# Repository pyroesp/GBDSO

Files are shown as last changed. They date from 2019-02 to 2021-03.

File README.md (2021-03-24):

# GBDSO

GBDSO Website : http://swelectronics.co.uk/Gameboy/DsoDemo/DsoDemo.htm  
GBDSO Elektor article : http://www.radanpro.com/Radan2400/TestShematics/GameBoyScope.pdf  
GBDSO BOM list (2019/02) : https://docs.google.com/spreadsheets/d/1vu9Xc1Mw5STfz_mAsAOrmmyRrHJMRS4_JKM7iif-KBE/edit#gid=0  

## Max Voltage Ratings

- +/- 16V on 1:1  
- +/- 50V on 10:1  

Do **NOT** exceed the max voltage ratings or you risk damaging the cartridge and the Game Boy.  
I'm not responsible if it blows up!  

## Schematic

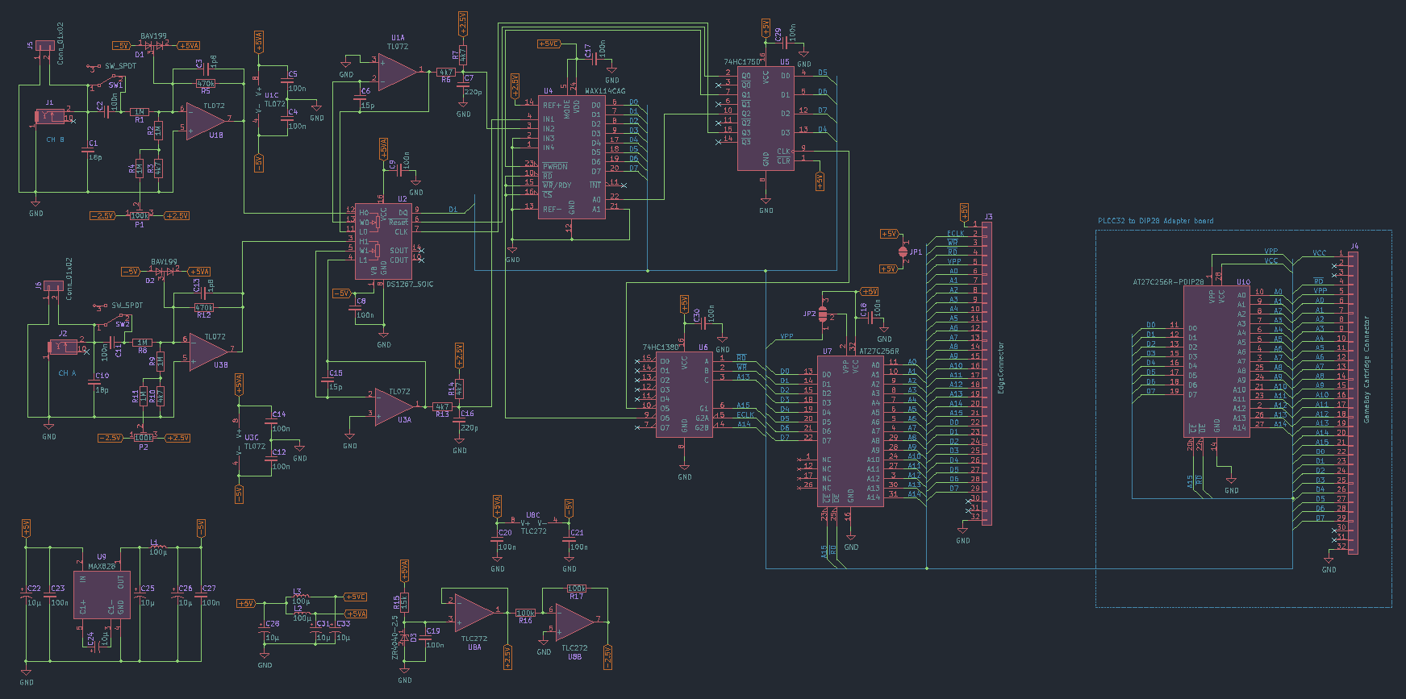
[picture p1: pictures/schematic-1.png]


## PCB

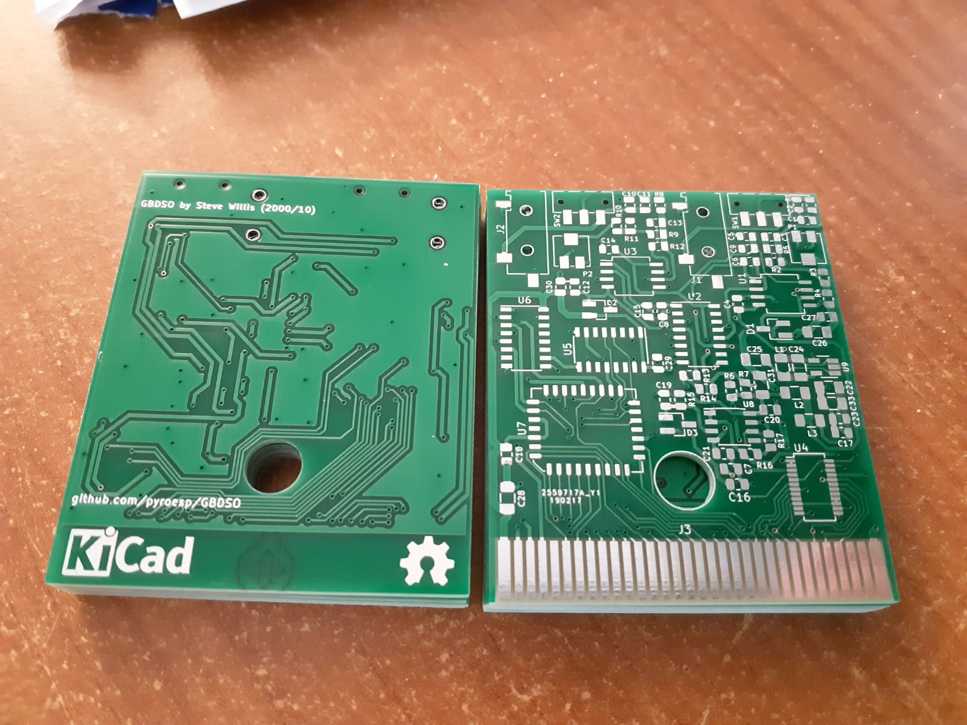
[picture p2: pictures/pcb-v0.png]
   
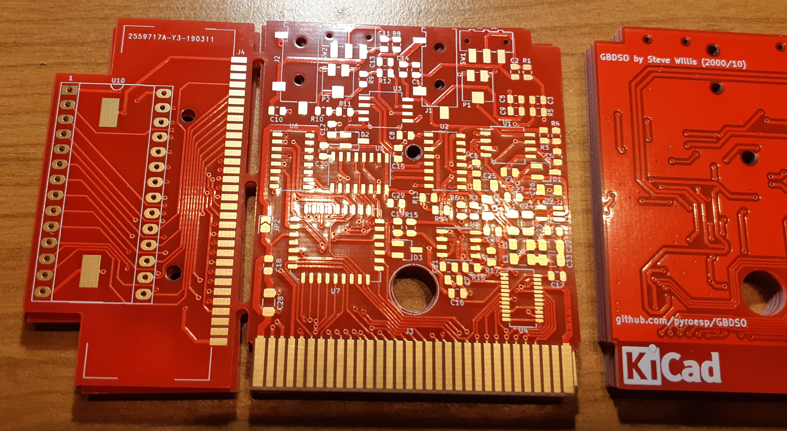
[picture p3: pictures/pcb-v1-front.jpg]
   
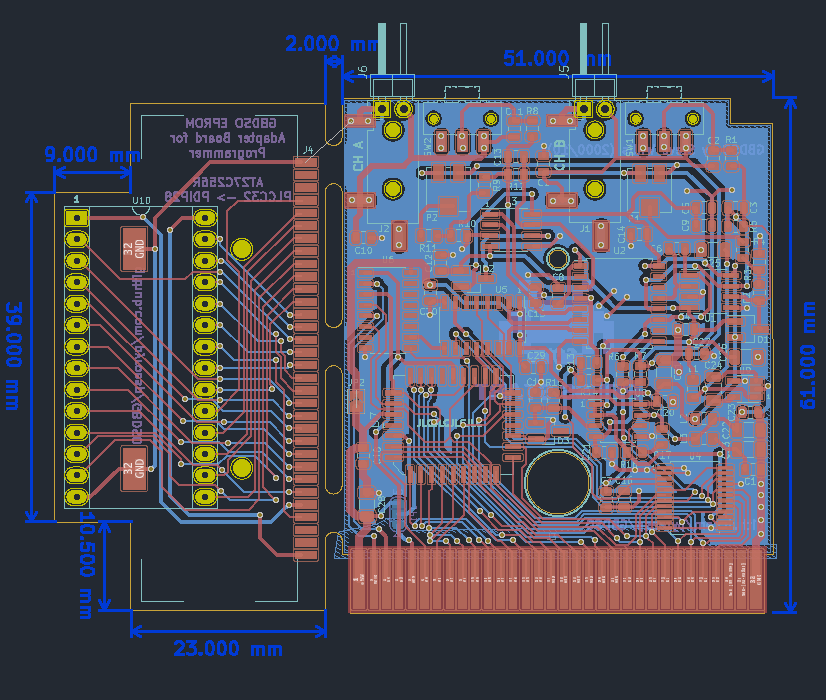
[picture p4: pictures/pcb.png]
  
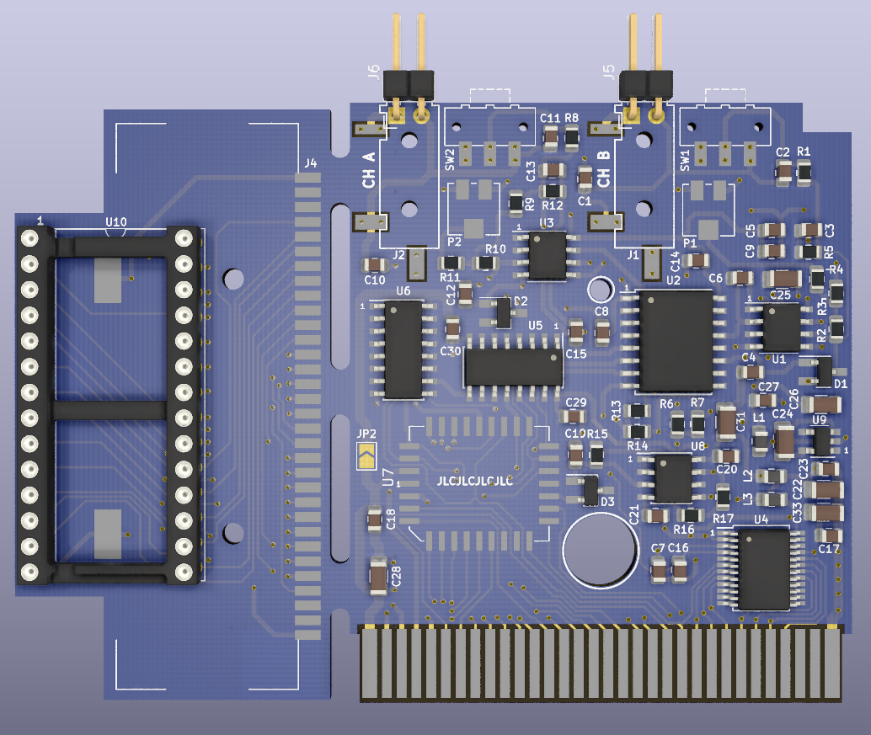
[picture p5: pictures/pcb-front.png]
  
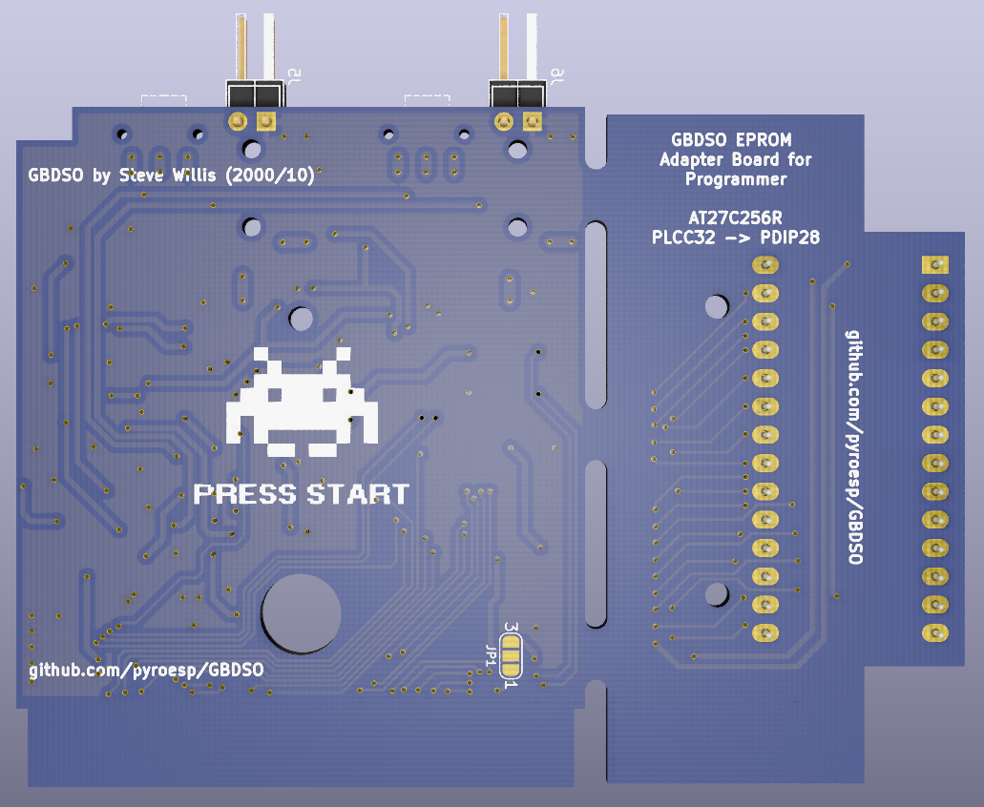
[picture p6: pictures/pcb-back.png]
   
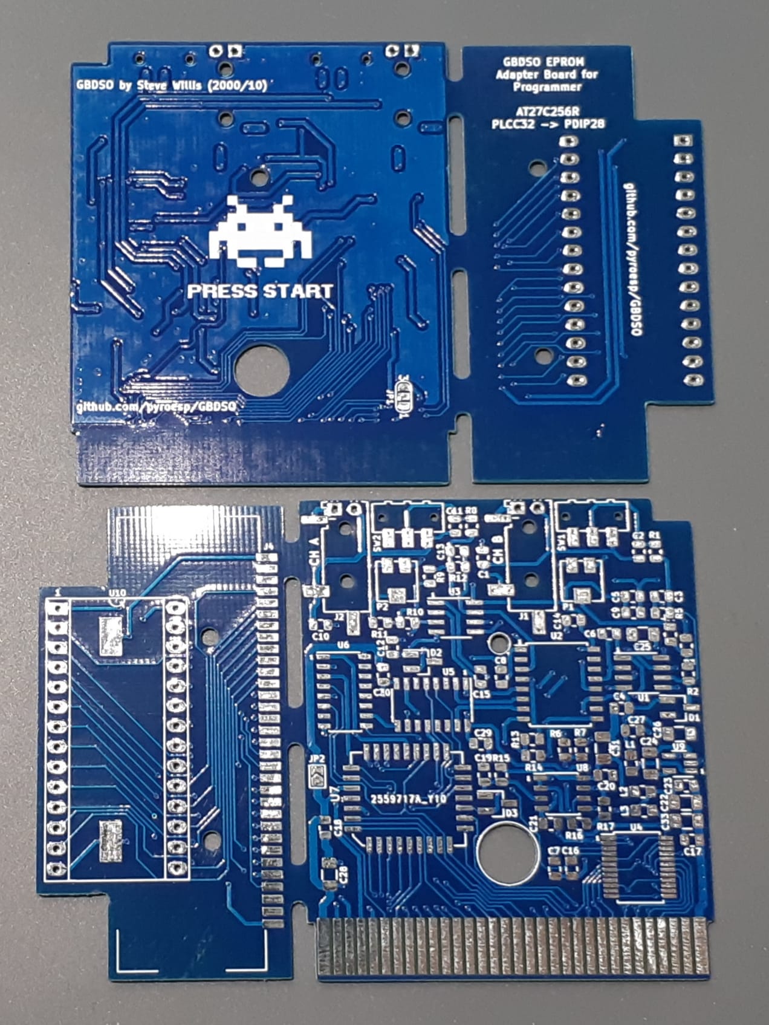
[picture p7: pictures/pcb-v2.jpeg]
   
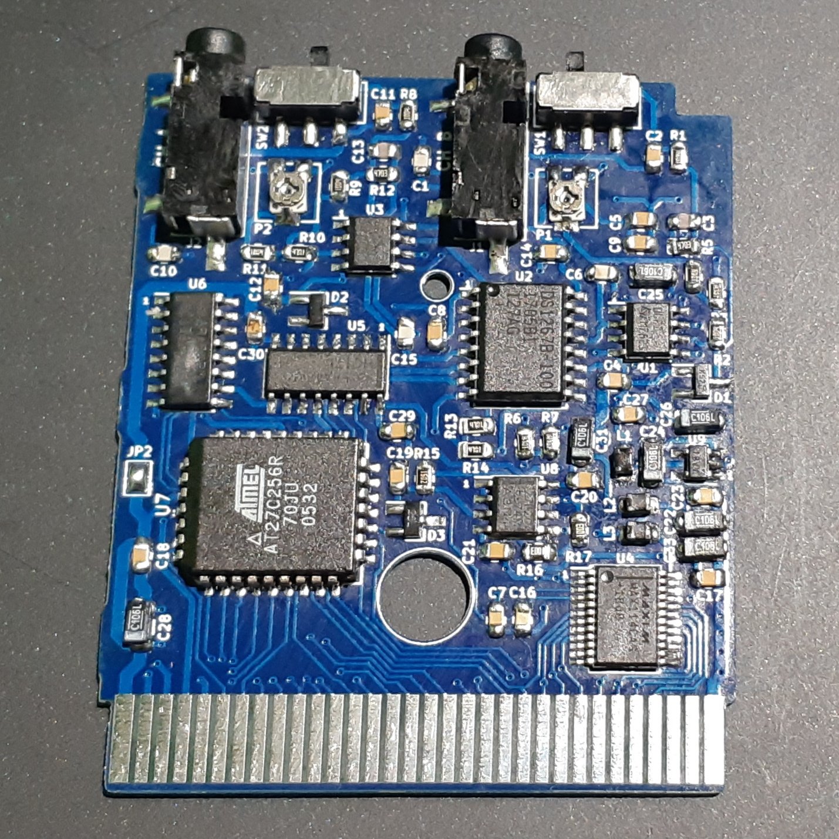
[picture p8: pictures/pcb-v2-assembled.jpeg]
   

## Game Boy test

Since the big v2 update on 2021/01/08, this GBDSO board works on both channels.  
See pictures below:  

   
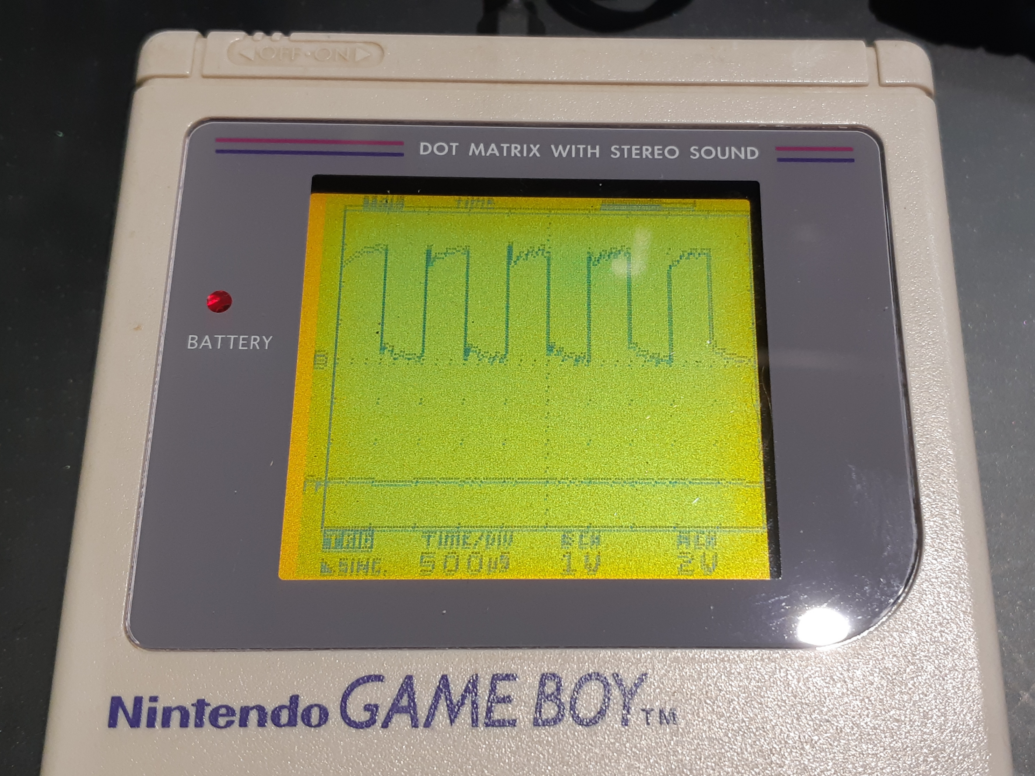
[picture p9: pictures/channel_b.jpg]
   

## Official game cart dimensions

Below you'll find the dimensions for the PCB of an official game (Pokémon Yellow JAP).  

 

## Programming the AT27C256R

The first jumper JP1 selects either 5V to pin 2 of the PROM (VPP) and VPP from the unused 5th edge connector.  
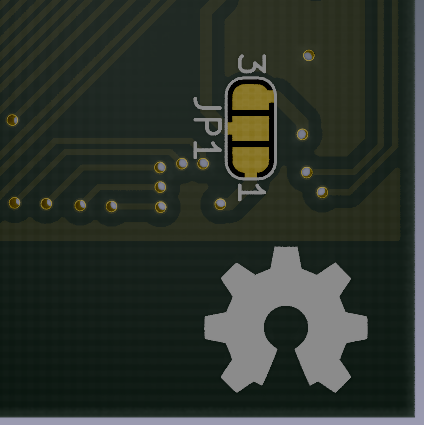
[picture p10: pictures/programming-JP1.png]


The second jumper JP2 cuts the power going to the rest of the board.  
While in programming mode, the PROM needs 6.5V to VCC and I'd rather not have it power to the rest of the board.  
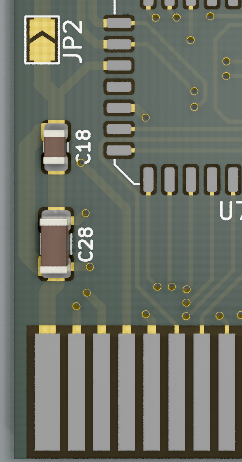
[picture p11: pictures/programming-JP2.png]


To program the PROM, leave JP2 open and set JP1 so that the edge connector VPP is connected to the PROM VPP.  
When programming is done, bridge JP2 and set JP1 so that 5V go to the PROM VPP.  

## GBDSO PROM to PDIP28  

Any decent Universal Programmer should be able to program the PROM on the cart.  
You can see the adapter board on the 3D rendered board above.  

The Game Boy connector uses the Xunbeifang GNI172 footprint made by **obskyr** from the <a href="https://github.com/gbdev/awesome-gbdev">gbdev discord</a>.  
You can find other Game Boy connectors made by **Gekkio** here: <a href="https://github.com/Gekkio/gekkio-kicad-libs">gekkio-kicad-libs</a>.  

The Xunbeifang GNI172 can be found on <a href="https://www.aliexpress.com/item/For-Nintendo-DS-NDSL-GBA-Game-Cartridge-Card-Reader-Slot-Repair-Part/32679592016.html">aliexpress</a>.

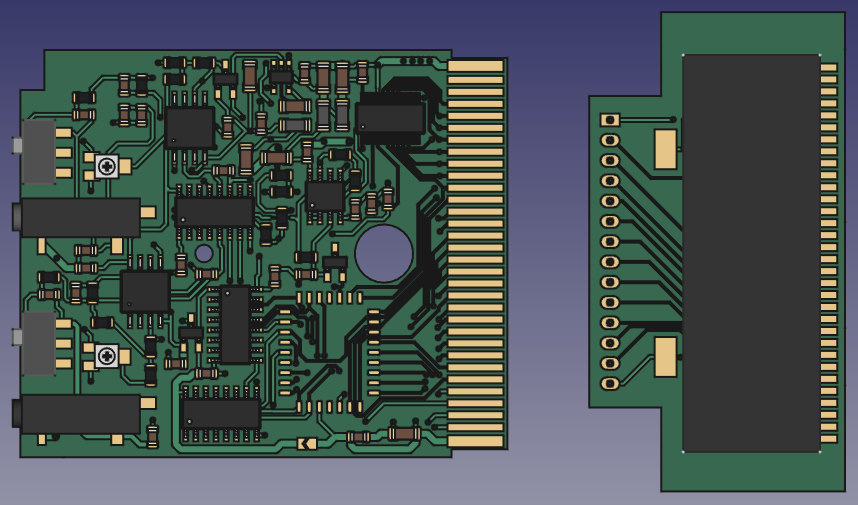
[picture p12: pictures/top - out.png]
  
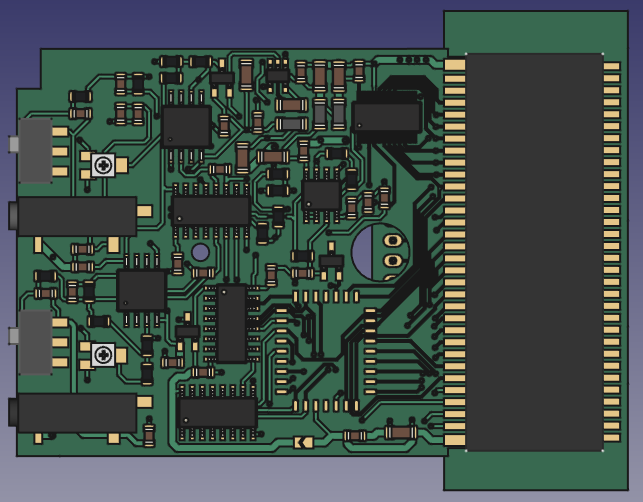
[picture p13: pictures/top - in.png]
  

To program the PROM, leave JP1 open and close JP2 as shown below.
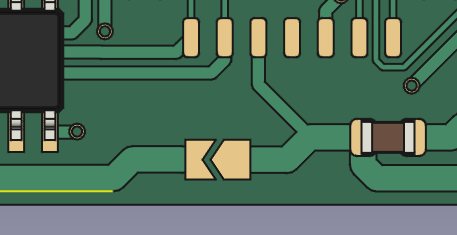
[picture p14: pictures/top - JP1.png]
  
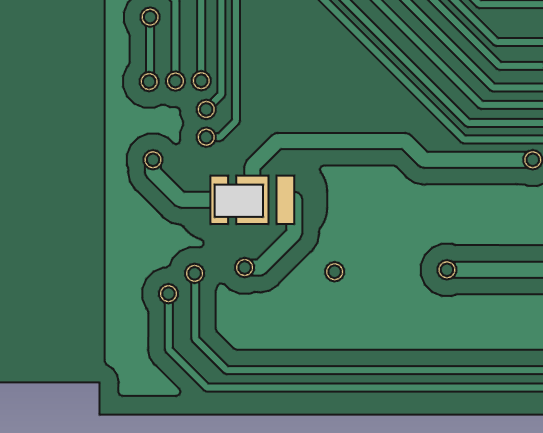
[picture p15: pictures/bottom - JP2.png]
  

Plug the adapter board into a Universal Programmer and set the target device to DIP28 AT27C256R.
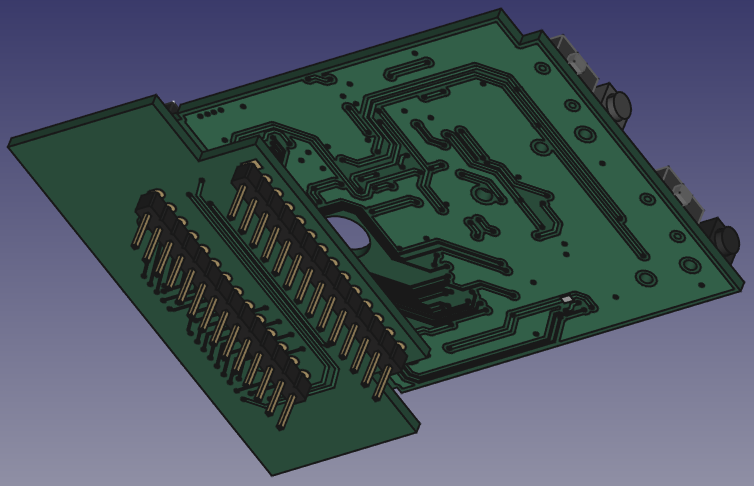
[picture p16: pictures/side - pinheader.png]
  

Note: This part of the board has not been tested yet, so I hope it works.

## Original GBDSO

Original GBDSO pictures from November 2000 courtesy of **Tauwasser** on the <a href="https://github.com/gbdev/awesome-gbdev">gbdev discord</a>.

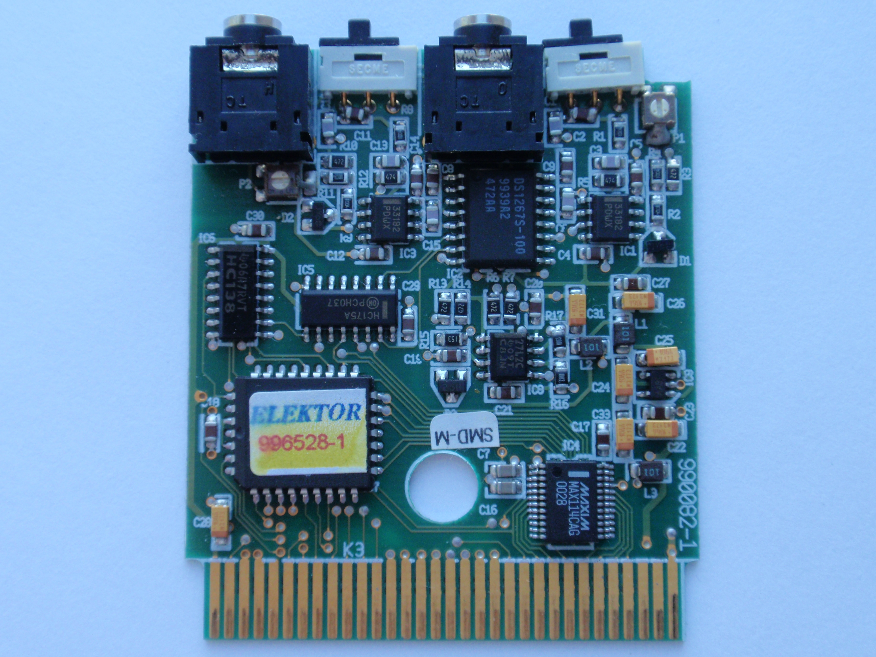
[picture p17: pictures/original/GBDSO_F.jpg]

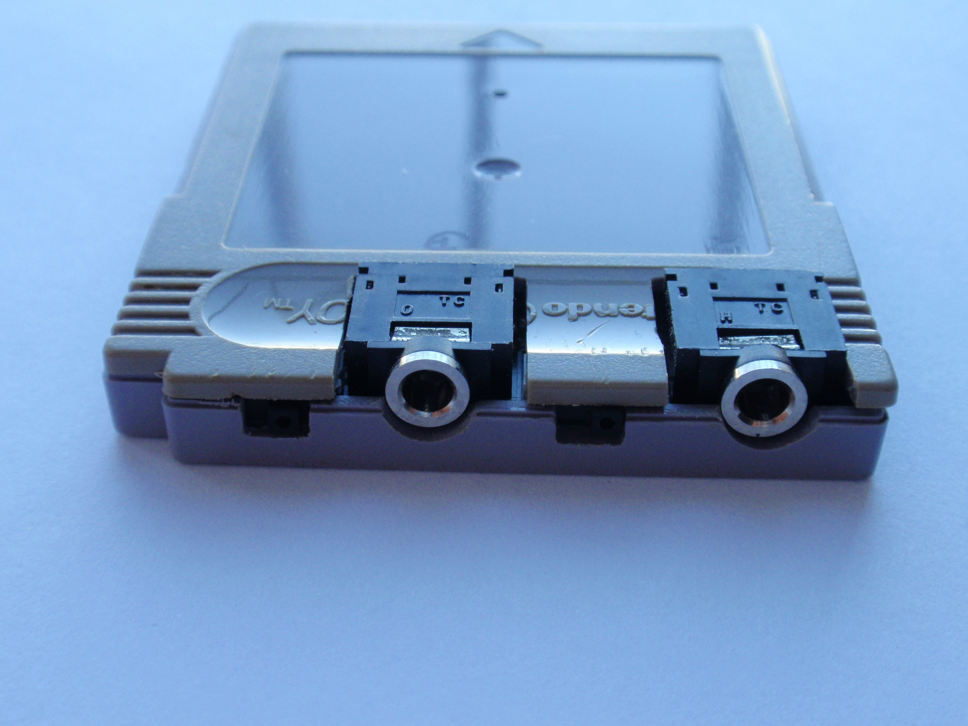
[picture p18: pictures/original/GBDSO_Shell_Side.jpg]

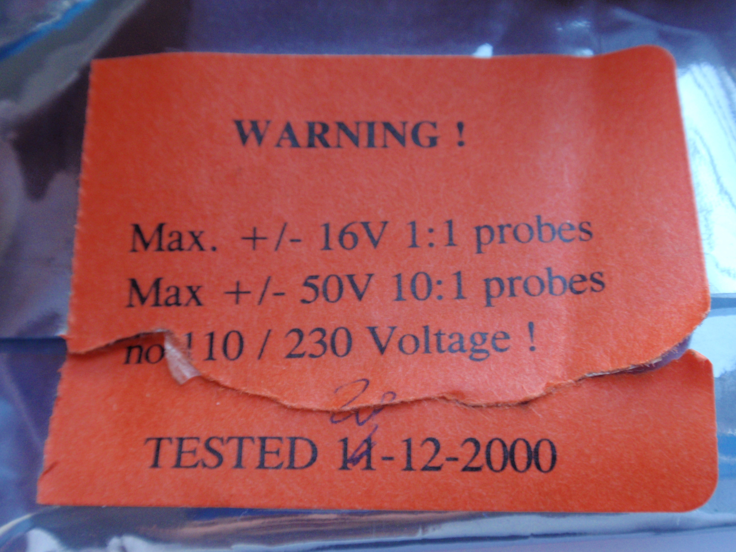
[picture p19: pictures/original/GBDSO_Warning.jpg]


## BOM list

| Label | Value / Name | Price per unit | Number | Total Price | Link |
|---|---|---|---|---|---|
| R1, R2, R4, R8, R9, R11 | 1M | 0.09 | 6 | 0.54 | https://www.digikey.be/product-detail/en/bourns-inc/CR0805-FX-1004ELF/CR0805-FX-1004ELFCT-ND/3740924 |
| R15 | 15k | 0.09 | 1 | 0.09 | https://www.digikey.be/product-detail/en/bourns-inc/CR0805-FX-1502ELF/CR0805-FX-1502ELFCT-ND/3740926 |
| R5, R12 | 470k | 0.09 | 2 | 0.18 | https://www.digikey.be/product-detail/en/RC0805FR-07470KL/311-470KCRCT-ND/730924/?itemSeq=284203171 |
| R3, R6, R7, R10, R13, R14 | 4k7 | 0.09 | 6 | 0.54 | https://www.digikey.be/product-detail/en/CR0805-FX-4701ELF/CR0805-FX-4701ELFCT-ND/3925402/?itemSeq=284203192 |
| R16, R17 | 100k | 0.09 | 2 | 0.18 | https://www.digikey.be/product-detail/en/yageo/RC0805FR-07100KL/311-100KCRCT-ND/730491 |
| P1, P2 | 100k | 0.24 | 2 | 0.48 | https://www.digikey.be/product-detail/en/bourns-inc/TC33X-2-104E/TC33X-104ECT-ND/612912 |
| C1, C10 | 18p | 0.12 | 2 | 0.24 | https://www.digikey.be/product-detail/en/yageo/CC0805JRNPO9BN180/311-1102-1-ND/303012 |
| C2, C4, C5, C8, C9, C11, C12, C14, C17-C21, C23, C27, C29, C30 | 100n | 0.09 | 17 | 1.53 | https://www.digikey.be/product-detail/en/CL21B104KBCNNNC/1276-1003-1-ND/3889089/?itemSeq=284204783 |
| C3, C13 | 1p8 | 0.09 | 2 | 0.18 | https://www.digikey.be/product-detail/en/samsung-electro-mechanics/CL21C1R8CBANNNC/1276-2599-1-ND/3890685 |
| C6, C15 | 15p | 0.1 | 2 | 0.2 | https://www.digikey.be/product-detail/en/wurth-electronics-inc/885012007052/732-7847-1-ND/5454474 |
| C7, C16 | 220p | 0.09 | 2 | 0.18 | https://www.digikey.be/product-detail/en/CL21B221KBANNNC/1276-2474-1-ND/3890560/?itemSeq=284205074 |
| C22, C24, C25, C26, C28, C31, C33 | 10µ 16V | 0.31 | 7 | 2.17 | https://www.digikey.be/product-detail/en/vishay-sprague/293D106X0016A2TE3/718-1956-1-ND/3985805 |
| L1, L2, L3 | 100µ | 0.18 | 3 | 0.54 | https://www.digikey.be/product-detail/en/taiyo-yuden/LBM2016T101J/587-1817-1-ND/1465287 |
| D1, D2 | BAV199 | 0.17 | 2 | 0.34 | https://www.digikey.be/product-detail/en/diodes-incorporated/BAV199-7-F/BAV199-FDICT-ND/1033647 |
| D3 | ZR25D01 -> ZR40402F25TA | 0.61 | 1 | 0.61 | https://www.digikey.be/product-detail/en/diodes-incorporated/ZR40402F25TA/ZR40402F25TACT-ND/243209 |
| IC1, IC3 | MC33182D -> TL072CDT | 0.42 | 2 | 0.84 | https://www.digikey.com/product-detail/en/stmicroelectronics/TL072CDT/497-2200-1-ND/599107 |
| IC2 | DS1267S100 -> DS1267BS-100+ | 5.52 | 1 | 5.52 | https://www.digikey.be/product-detail/en/maxim-integrated/DS1267BS-100/DS1267BS-100-ND/5049982 |
| IC4 | MAX114CAG | 6.9 | 1 | 6.9 | https://www.digikey.be/product-detail/en/maxim-integrated/MAX114CAG/MAX114CAG-ND/1428095 |
| IC5 | 74HC175D | 0.41 | 1 | 0.41 | https://www.digikey.be/product-detail/en/texas-instruments/SN74HC175DR/296-14840-1-ND/562676 |
| IC6 | 74HC138D | 0.34 | 1 | 0.34 | https://www.digikey.be/product-detail/en/texas-instruments/SN74HC138D/296-1193-5-ND/277220 |
| IC7 | AT27C256R-12JC -> AT27C256R-70JU | 1.2 | 1 | 1.2 | https://www.digikey.be/product-detail/en/microchip-technology/AT27C256R-70JU/AT27C256R-70JU-ND/1008583 |
| IC8 | TLC27L2CD | 0.86 | 1 | 0.86 | https://www.digikey.be/product-detail/en/texas-instruments/TLC27L2CDR/296-1316-1-ND/404950 |
| IC9 | MAX828EUK | 4.5 | 1 | 4.5 | https://www.digikey.be/product-detail/en/MAX828EUK%2bT/MAX828EUK%2bTCT-ND/2699369/?itemSeq=284207452 |
| S1, S2 | Slide switch 1 change-over contact | 0.49 | 2 | 0.98 | https://www.digikey.be/product-detail/en/c-k/JS102011SAQN/401-1999-1-ND/1640114 |
| K1, K2 | 3.5mm stereo socket -> mono smd | 0.88 | 2 | 1.76 | https://www.digikey.be/product-detail/en/cui-inc/MJ-3523-SMT-TR/CP-3523MJCT-ND/669691 |

Total Price: 31.31€<br>			
Total Components: 70

## Replacement parts

The input opamps MC33182D is not being sold anymore, at least not on digikey.  
So looking around I thought the TL062 would be a nice replacement but the numbers weren't quite similar.  
I've looked at the TL072 and this one looks pretty good, the only downside is that it isn't a low power opamp.  

If we compare the current consumption from the TL072 and the MC33182D, the TL072 uses 5 times more current (1.4mA typ.) than the MC33182D (420µA).  

Looking further into the MC33182D I found this old forum post talking about replacing it on a GBDSO : [edaboard forum](https://www.edaboard.com/showthread.php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)  
They talked about the TL082, LF412, TLE2082A and TLE2602. Someone used that last one as a replacement for the MC33182D, although digikey has it priced at around 2$ per unit...  

Looking at the information page on TI's website, this is what they say:  
> The TL206x devices are pin-compatible with other TI BiFETs; they can be used to double the bandwidth of TL06x and TL03x circuits, or to reduce power consumption of TL05x, TL07x, and TL08x circuits by nearly 90%.  

That power reduction is crucial for long lasting batteries.  
For now though, I'll try the TL062 I currently have and will try the TL072 on a later date.  
I'll also try to find a suitable, pin-compatible, low power replacement opamp for the TL072.

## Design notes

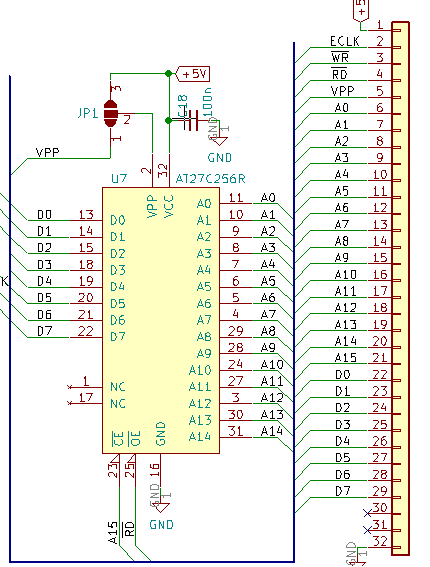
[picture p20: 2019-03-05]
pictures/schematic-eprom.png

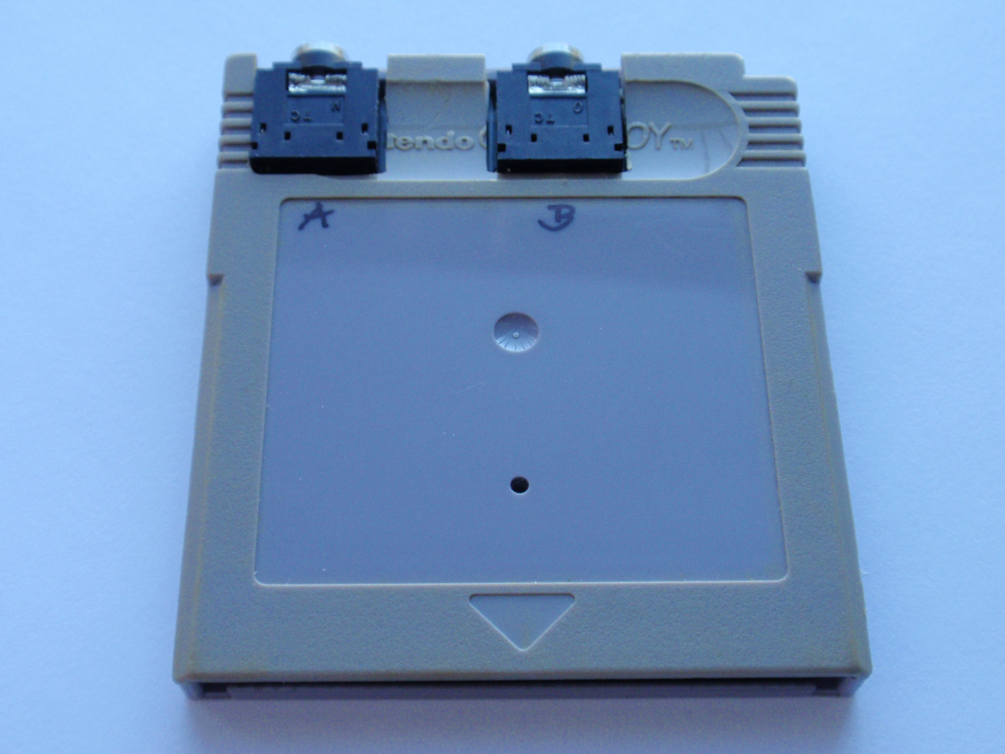
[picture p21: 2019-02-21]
pictures/original/GBDSO_Shell_Top.jpg

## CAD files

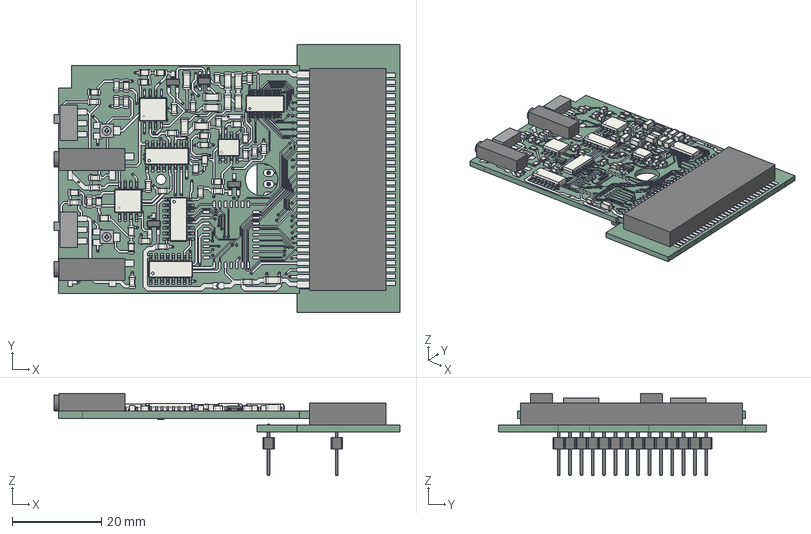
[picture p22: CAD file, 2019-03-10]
freecad/adapter board render/GBDSO 3D model.FCStd
77.5 x 60.0 x 18.4 mm
Pcb
topTracks
botTracks
PinHeader_1x14_P254mm_Vertical
PinHeader_1x14_P254mm_Vertical001
Pcb001
topTracks001
botTracks001
C26_C_1206_3216Metric_5C660075
C23_C_0805_2012Metric_5C8521D1
C1_C_0805_2012Metric_5C865207
C2_C_0805_2012Metric_5C6688FF
C3_C_0805_2012Metric_5C868FB3
C4_C_0805_2012Metric_5C65FEFF
C5_C_0805_2012Metric_5C868FE3
C6_C_0805_2012Metric_5C878DF4
C7_C_0805_2012Metric_5C65FF32
C8_C_0805_2012Metric_5C65FF43
C9_C_0805_2012Metric_5C869043
C10_C_0805_2012Metric_5C84D646
C11_C_0805_2012Metric_5C84B3D2
C12_C_0805_2012Metric_5C65FF87
C13_C_0805_2012Metric_5C65FF98
C14_C_0805_2012Metric_5C8441C3
C15_C_0805_2012Metric_5C65FFBA
C16_C_0805_2012Metric_5C830B5C
C17_C_0805_2012Metric_5C85263F
C18_C_0805_2012Metric_5C65FFED
C19_C_0805_2012Metric_5C6682C5
C20_C_0805_2012Metric_5C66000F
C21_C_0805_2012Metric_5C660020
C22_C_1206_3216Metric_5C8533CB
C24_C_1206_3216Metric_5C660053
C25_C_1206_3216Metric_5C660064
C27_C_0805_2012Metric_5C660086
C28_C_1206_3216Metric_5C86CBE6
C29_C_0805_2012Metric_5C833A80
C30_C_0805_2012Metric_5C662F06
C31_C_1206_3216Metric_5C6600CA
C33_C_1206_3216Metric_5C853338
D1_SOT_23_5C6600F0
D2_SOT_23_5C660105
D3_SOT_23_5C831958
L1_L_1206_3216Metric_5C70B5E1
L2_L_1206_3216Metric_5C66017C
L3_L_1206_3216Metric_5C66018D
R1_R_0805_2012Metric_5C66A901
R2_R_0805_2012Metric_5C86A09A
R3_R_0805_2012Metric_5C660208
R4_R_0805_2012Metric_5C660219
R5_R_0805_2012Metric_5C869013
R6_R_0805_2012Metric_5C66023B
R7_R_0805_2012Metric_5C66024C
R8_R_0805_2012Metric_5C84B3A2
R9_R_0805_2012Metric_5C8378E1
R10_R_0805_2012Metric_5C66027F
R11_R_0805_2012Metric_5C660290
R12_R_0805_2012Metric_5C837911
R13_R_0805_2012Metric_5C6602B2
R14_R_0805_2012Metric_5C66A051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

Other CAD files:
freecad/pcb dimensions/pcb dimensions.FCStd

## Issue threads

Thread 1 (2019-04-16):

Digital Potentiometer footprint

pyroesp, 2019-04-16:
Footprint should be wide SOIC 16, which is not currently used.

pyroesp, 2019-04-18:
Should be fixed in commit 99

Closed 2019-04-18.

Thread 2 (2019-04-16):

Digital Potentiometer symbol swapped pins

pyroesp, 2019-04-16:
The DS1267 has pin 12 and pin 13 swapped in the symbol and thus also in the footprint.

Issue has been opened on the KiCad github page.

pyroesp, 2019-04-18:
Issue opened and PR done in the KiCad repo to get this fixed.
For now it should be fixed in commit 99

Closed 2019-04-18.

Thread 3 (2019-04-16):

MAX114CAG ADC footprint

pyroesp, 2019-04-16:
The ADC needs a wide SSOP24 footprint

pyroesp, 2019-04-18:
Should be fixed in commit 99

Closed 2019-04-18.

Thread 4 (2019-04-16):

TL062 opamps footprint

pyroesp, 2019-04-16:
Opamps need SOIC8 footprint.
Currently, they use SO8, which is ok-ish, just a bit too wide.

pyroesp, 2019-04-18:
Should be fixed in commit 99

Closed 2019-04-18.

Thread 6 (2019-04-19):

Small hole is not at the correct position

pyroesp, 2019-04-19:
Looking at the cartridge dimensions I totally messed up the height of the small hole.
Currently it's set at 23 mm, which is incorrect.
It's supposed to be at 19 mm from the top...

pyroesp, 2019-04-20:
Fixed in PR #7

Closed 2019-04-20.

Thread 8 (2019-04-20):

Add silkscreen information

pyroesp, 2019-04-20:
Currently there's no silkscreen showing what connecter is which channel.
Same for the switch, nothing tells the user what is selected, AC or DC.

Other silkscreen text might be useful, like:
- the pins of the edge connector
- input signal to the opamps
- digital potentiometer inputs per channel
- output of opamp to ADC
- ...

pyroesp, 2020-04-02:
There's not really much space for this. I've added CH A and CH B to the silkscreen next to the input jacks and for now I'm going to leave it at that.

Closed 2020-04-02.

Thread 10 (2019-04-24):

Channels not responding

pyroesp, 2019-04-24:
As of today the GBDSO boots up fine, but neither channels work.
Channel A is glitching an unresponsive.
Channel B doesn't do much, the signal stays at GND level.

This needs to be investigated to see if it's an issue:
- in the schematic
- in the routing of the PCB
- in the parts/IC
- ...

pyroesp, 2019-10-22:
I have extra boards lying around somewhere.
To troubleshoot the circuit, some parts could be built on those boards to debug.
For example, build the ADC circuit and troubleshoot that. Do the same for other ICs.

pyroesp, 2021-01-08:
There were a couple of errors in the schematic, which I'm hoping are resolved.
The boards still needs testing, so this issue stays open.

pyroesp, 2021-01-08:
Just for logging purposes, I found one if not the big error :
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

pyroesp, 2021-01-09:
This should be fixed with the big v2 update. See the pictures of me measuring a square wave on the game boy.

Closed 2021-01-09.

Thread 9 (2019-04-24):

Schematic not up to date

pyroesp, 2019-04-24:
see title

pyroesp, 2019-10-18:
Here we are 6 months later and I'm not sure wtf this bug is, thanks past self...
I think it's the schematic image that's not up to date, but I'm not sure.

Closed 2020-04-02.

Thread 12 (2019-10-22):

Add test pads in the circuit

pyroesp, 2019-10-22:
If possible try adding test pads in the circuit to troubleshoot the board.
Some location for test pad could be output of opamps, control signals for ADC, ...

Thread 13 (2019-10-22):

Hide JLCPCB order number

pyroesp, 2019-10-22:
Hide JLCPCB order by writing "JLCJLCJLCJLC" somewhere on the silkscreen.
Maybe under the cartridge connector of the adapter / programmer board ?

pyroesp, 2021-01-08:
this one has been done in a previous commit

Closed 2021-01-08.

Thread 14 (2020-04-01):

TL062 not suitable replacement

pyroesp, 2020-04-01:
The original opamp MC33182D has a gain bandwidth of 4MHz and slew rate of 10V/µs.
The replacement I chose, the TL062, only goes up to 1MHz and has a slew rate of only 3,5V/µs.

A better replacement is the TL072 with 4MHz bandwidth and 13V/µs slew rate.

TODO : Replace TL062 by TL072

Closed 2020-04-02.

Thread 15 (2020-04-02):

Enhancement idea for connectors

Switching-Power, 2020-04-02:
Hi i have an original GBDSO and modded it to have MSX input connectors.
If you like it you can use the idea in your design.

The nice thing about the MSX connectors is that they are small enough to not stick out the top of the cartridge, you only need to file the front part round.

MSX connectors: https://www.aliexpress.com/item/1987184846.html
Ready made probes are also available: https://www.aliexpress.com/item/4000236094377.html
And a new case you can put on the BOM: https://www.aliexpress.com/item/32691348089.html

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

pyroesp, 2020-04-02:
That's pretty cool, but I don't know how I could use those and keep the header pins.

Although that connector would give me more space to move things around...
I'll have to think about this... but thanks for showing your GBDSO, it's awesome.

pyroesp, 2020-04-02:
So I don't forget to look at this: the connector is actually called MCX or MMCX, Right Angle Edge Mount.

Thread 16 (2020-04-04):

A14 and A15 switched on DEMUX

pyroesp, 2020-04-04:
A14 and A15 are switched on the DEMUX 74HC138.
Pin 6 should be A15 and pin 4 A14.

pyroesp, 2020-04-04:
Not yet fixed in PCB, my bad

Closed 2020-04-04.

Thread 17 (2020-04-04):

BAV199 is connected to +5V instead of +5VA

pyroesp, 2020-04-04:
BAV199 is connected to +5V instead of +5VA for both TL072

pyroesp, 2020-04-04:
Not yet fixed in PCB, my bad

Closed 2020-04-04.

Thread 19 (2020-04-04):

Use 3 pin of switch for grounding channel input

pyroesp, 2020-04-04:
Use the 3rd pin of the SPDT switch, to ground the channel.

To calibrate the GBDSO you need to connect the input to ground.
The original schematic only had a SPST switch.
This one has an SPDT switch so I can use the 3rd pin to GND the signal.

pyroesp, 2020-04-04:
This improvement has been done in commit a82cf03

Closed 2020-04-04.

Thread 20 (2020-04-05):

Make pins of the EPROM longer

pyroesp, 2020-04-05:
The 27C256 EPROM was not easy to solder as I couldn't get my soldering iron on the pads.
If possible make the pins slightly longer to make it easier to hand solder.

pyroesp, 2020-04-07:
Should be fixed with last commit d991ba8

Closed 2020-04-07.

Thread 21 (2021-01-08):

AC/DC switch connected to GND

pyroesp, 2021-01-08:
When adding the header pins on the channels I connected one side to the switch and ground.
At the time I didn't see an issue with it, but this completely wrong.
With this you can now only select between GND and DC. AC coupling the signal does not work anymore!

This needs to be fixed.

pyroesp, 2021-01-08:
should be fixed in the big v2 commit 7f2ef27

Closed 2021-01-08.

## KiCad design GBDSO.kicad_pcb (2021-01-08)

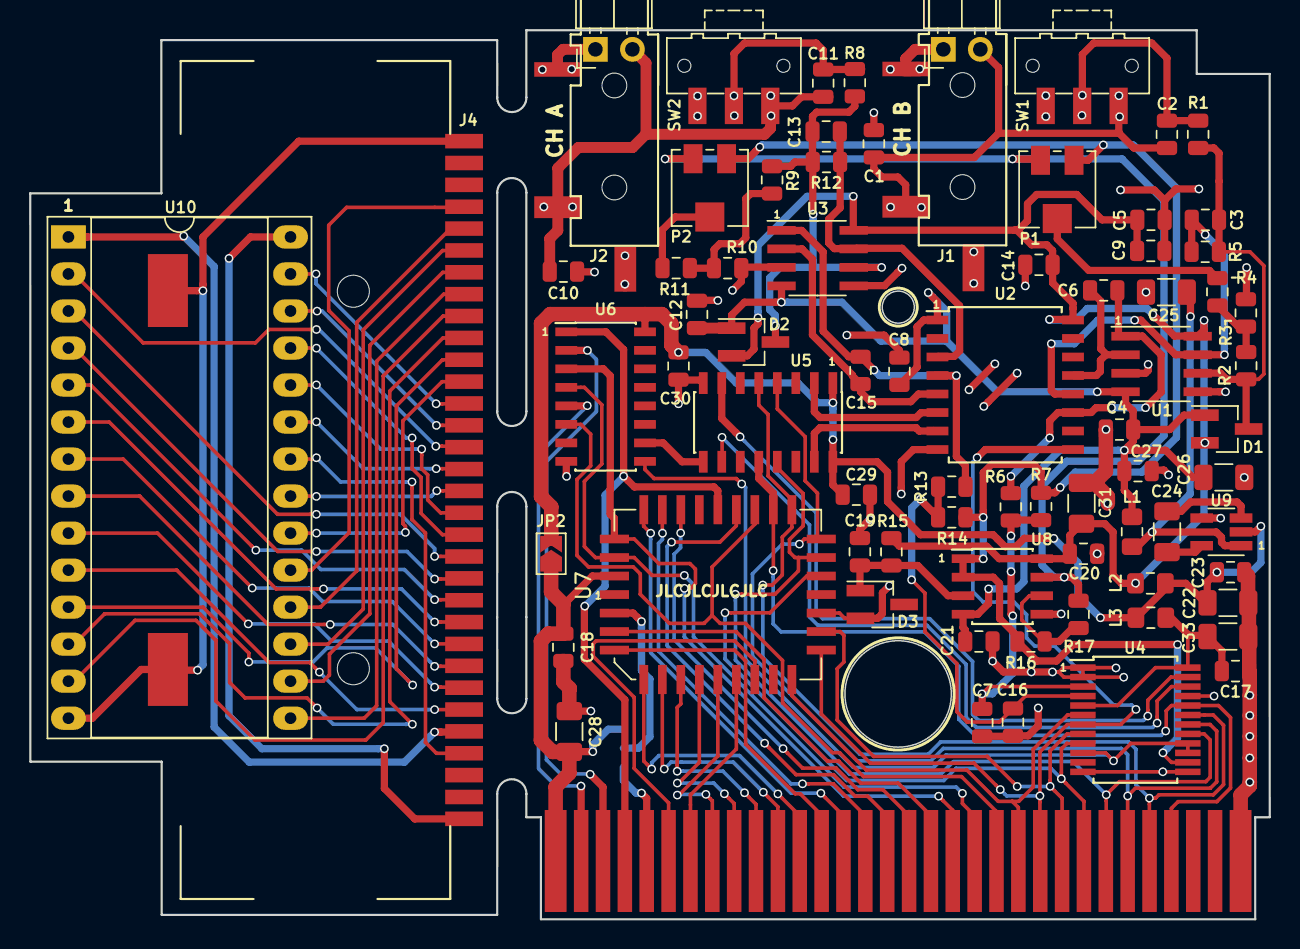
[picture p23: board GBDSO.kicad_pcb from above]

Board: 2 copper layers, 85.0 x 61.0 mm, 77 parts (1 on the bottom side), 92 nets.

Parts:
C1, C10: 18p; C_0805_2012Metric
C2, C4, C5, C8, C9, C11, C12, C14, C17, C18, C19, C20, C21, C23, C27, C29, C30: 100n; C_0805_2012Metric
C3, C13: 1p8; C_0805_2012Metric
C6, C15: 15p; C_0805_2012Metric
C7, C16: 220p; C_0805_2012Metric
C22, C24, C25, C26, C28, C31, C33: 10µ; C_1206_3216Metric
D1, D2: BAV199; SOT-23_Handsoldering
D3: ZR4040-2.5; SOT-23_Handsoldering
J1, J2: MJ-3523-SMT-TR
J3: EdgeConnector; GB_EdgeConnector
J4: GameBoy Cartridge Connector; Game_Boy_Cartridge_Slot_Xunbeifang_GNI172
J5, J6: Conn_01x02; PinHeader_1x02_P2.54mm_Horizontal
JP1: SolderJumper_3_Open; SolderJumper-3_P1.3mm_Open_RoundedPad1.0x1.5mm_NumberLabels
JP2: SolderJumper_2_Open; SolderJumper-2_P1.3mm_Open_TrianglePad1.0x1.5mm
L1, L2, L3: 100µ; L_0805_2012Metric_Pad1.15x1.40mm_HandSolder
P1, P2: 100k; Potentiometer_Vishay_TS53YJ_Vertical
R1, R2, R4, R8, R9, R11: 1M; R_0805_2012Metric
R3, R6, R7, R10, R13, R14: 4k7; R_0805_2012Metric
R5, R12: 470k; R_0805_2012Metric
R15: 15k; R_0805_2012Metric
R16, R17: 100k; R_0805_2012Metric
SW1, SW2: SW_SPDT; SW_SPDT_CK-JS102011SAQN
U1, U3: TL072; SOIC-8_3.9x4.9mm_P1.27mm
U2: DS1267_SOIC; SOIC-16W_7.5x10.3mm_P1.27mm
U4: MAX114CAG; SSOP-24_5.3x8.2mm_P0.65mm
U5: 74HC175D; SOIC-16_3.9x9.9mm_P1.27mm
U6: 74HC138D; SOIC-16_3.9x9.9mm_P1.27mm
U7: AT27C256R; PLCC-32_HandSolder
U8: TLC272; SOIC-8_3.9x4.9mm_P1.27mm
U9: MAX828; SOT-23-5_HandSoldering
U10: AT27C256R-PDIP28; DIP-28_W15.24mm_Socket_LongPads

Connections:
+2.5V: P1.3, P2.3, R7.2, R14.2, R16.2, U4.14, U8.1, U8.2
+5V: C18.1, C22.1, C23.1, C28.1, C29.1, C30.1, J3.1, JP1.3, JP2.1, JP2.2, L2.1, L3.1, U5.1, U5.16, U6.16, U7.32, U9.2
+5VA: C5.1, C9.1, C14.1, C20.1, C31.1, D1.2, D2.2, L2.2, R15.2, U1.8, U2.16, U3.8, U8.8
+5VC: C17.1, C33.1, L3.2, U4.5, U4.24
-2.5V: P1.1, P2.1, R17.1, U8.7
-5V: C4.2, C8.1, C12.2, C21.1, C26.1, C27.1, D1.1, D2.1, L1.2, U1.4, U2.1, U3.4, U8.4
/GBDSO Cartridge/A0: J3.6, U7.11
/GBDSO Cartridge/A1: J3.7, U7.10
/GBDSO Cartridge/A2: J3.8, U7.9
/GBDSO Cartridge/A3: J3.9, U7.8
/GBDSO Cartridge/A4: J3.10, U7.7
/GBDSO Cartridge/A5: J3.11, U7.6
/GBDSO Cartridge/A6: J3.12, U7.5
/GBDSO Cartridge/A7: J3.13, U7.4
/GBDSO Cartridge/A8: J3.14, U7.29
/GBDSO Cartridge/A9: J3.15, U7.28
/GBDSO Cartridge/A10: J3.16, U7.24
/GBDSO Cartridge/A11: J3.17, U7.27
/GBDSO Cartridge/A12: J3.18, U7.3
/GBDSO Cartridge/A13: J3.19, U6.3, U7.30
/GBDSO Cartridge/A14: J3.20, U6.4, U7.31
/GBDSO Cartridge/A15: J3.21, U6.6, U7.23
/GBDSO Cartridge/D0: J3.22, U4.6, U7.13
/GBDSO Cartridge/D1: J3.23, U2.9, U4.7, U7.14
/GBDSO Cartridge/D2: J3.24, U4.8, U7.15
/GBDSO Cartridge/D3: J3.25, U4.9, U7.18
/GBDSO Cartridge/D4: J3.26, U4.17, U5.13, U7.19
/GBDSO Cartridge/D5: J3.27, U4.18, U5.4, U7.20
/GBDSO Cartridge/D6: J3.28, U4.19, U5.5, U7.21
/GBDSO Cartridge/D7: J3.29, U4.20, U5.12, U7.22
/GBDSO Cartridge/ECLK: J3.2, U6.5
/GBDSO Cartridge/VPP: J3.5, JP1.1
/GBDSO Cartridge/~RD: J3.4, U6.1, U7.25
/GBDSO Cartridge/~WR: J3.3, U6.2
/GBDSO EPROM Adapter Board/A0: J4.6, U10.10
/GBDSO EPROM Adapter Board/A1: J4.7, U10.9
/GBDSO EPROM Adapter Board/A2: J4.8, U10.8
/GBDSO EPROM Adapter Board/A3: J4.9, U10.7
/GBDSO EPROM Adapter Board/A4: J4.10, U10.6
/GBDSO EPROM Adapter Board/A5: J4.11, U10.5
/GBDSO EPROM Adapter Board/A6: J4.12, U10.4
/GBDSO EPROM Adapter Board/A7: J4.13, U10.3
/GBDSO EPROM Adapter Board/A8: J4.14, U10.25
/GBDSO EPROM Adapter Board/A9: J4.15, U10.24
/GBDSO EPROM Adapter Board/A10: J4.16, U10.21
/GBDSO EPROM Adapter Board/A11: J4.17, U10.23
/GBDSO EPROM Adapter Board/A12: J4.18, U10.2
/GBDSO EPROM Adapter Board/A13: J4.19, U10.26
/GBDSO EPROM Adapter Board/A14: J4.20, U10.27
/GBDSO EPROM Adapter Board/A15: J4.21, U10.20
/GBDSO EPROM Adapter Board/D0: J4.22, U10.11
/GBDSO EPROM Adapter Board/D1: J4.23, U10.12
/GBDSO EPROM Adapter Board/D2: J4.24, U10.13
/GBDSO EPROM Adapter Board/D3: J4.25, U10.15
/GBDSO EPROM Adapter Board/D4: J4.26, U10.16
/GBDSO EPROM Adapter Board/D5: J4.27, U10.17
/GBDSO EPROM Adapter Board/D6: J4.28, U10.18
/GBDSO EPROM Adapter Board/D7: J4.29, U10.19
/GBDSO EPROM Adapter Board/VCC: J4.1, U10.28
/GBDSO EPROM Adapter Board/VPP: J4.5, U10.1
/GBDSO EPROM Adapter Board/~RD: J4.4, U10.22
GND: C1.2, C4.1, C5.2, C7.2, C8.2, C9.2, C10.2, C12.1, C14.2, C16.2, C17.2, C18.2, C19.2, C20.2, C21.2, C22.2, C23.2, C25.2, C26.2, C27.2, C28.2, C29.2, C30.2, C31.2, C33.2, D3.2, J1.1, J2.1, J3.32, J4.32, J5.1, J6.1, R3.1, R10.1, U1.3, U1.5, U2.8, U3.3, U3.5, U4.1, U4.2, U4.12, U4.13, U4.21, U5.8, U6.8, U7.16, U8.5, U9.4, U10.14
unnamed: C1.1, C2.1, J1.2, J5.2, SW1.1
unnamed: C2.2, R1.2, SW1.2
unnamed: C3.1, D1.3, R1.1, R2.2, R5.2, U1.6
unnamed: C3.2, R5.1, U1.7, U2.12
unnamed: C6.1, U1.2, U2.13
unnamed: C6.2, R6.2, U1.1, U2.11
unnamed: C7.1, R6.1, R7.1, U4.3
unnamed: C10.1, C11.2, J2.2, J6.2, SW2.1
unnamed: C11.1, R8.2, SW2.2
unnamed: C13.1, D2.3, R8.1, R9.2, R12.2, U3.6
unnamed: C13.2, R12.1, U2.3, U3.7
unnamed: C15.1, R13.2, U2.4, U3.1
unnamed: C15.2, U2.5, U3.2
unnamed: C16.1, R13.1, R14.1, U4.4
unnamed: C19.1, D3.1, R15.1, U8.3
unnamed: C24.1, U9.5
unnamed: C24.2, U9.3
unnamed: C25.1, L1.1, U9.1
unnamed: JP1.2, U7.2
unnamed: P1.2, R4.1
unnamed: P2.2, R11.1
unnamed: R2.1, R3.2, R4.2
unnamed: R9.1, R10.2, R11.2
unnamed: R16.1, R17.2, U8.6
unnamed: U2.6, U5.2
unnamed: U2.7, U5.15
unnamed: U4.10, U4.15, U4.16, U6.9
unnamed: U4.22, U5.10
unnamed: U4.23, U5.7
unnamed: U5.9, U6.10

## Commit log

2019-02-11 added project, schematic, netlist and PCB files
    [GBDSO.kicad_pcb, GBDSO.sch]
2019-02-11 made the BAV199 diodes smaller
2019-02-11 minor update to voltage reference component
2019-02-11 update symbole table and add footprint table
2019-02-11 updated schematic
    [GBDSO.sch]
2019-02-11 add new component : SMD mono 3.5mm jack
2019-02-11 updated pcb with new and all footprints
    [GBDSO.kicad_pcb]
2019-02-12 finished schematic, need to double check to be sure
    [GBDSO.sch]
2019-02-12 updated pcb
    [GBDSO.kicad_pcb]
2019-02-13 updated schematic, corrected some errors
    [GBDSO.sch]
2019-02-15 updated PCB, changed track width, started with routing power and GND. Also, bottom layer is a GND plane
    [GBDSO.kicad_pcb]
2019-02-16 update footprint table
2019-02-16 update footprint audio jack
2019-02-16 updated schematic, new generated netlist, finished pcb
    [GBDSO.kicad_pcb, GBDSO.sch]
2019-02-16 created new footprint for GB edge connector
2019-02-16 add images of PCB and schematic
2019-02-16 final update of pcb, updated images
    [GBDSO.kicad_pcb]
2019-02-16 generated gerber files for production
    [GBDSO-B.Cu.gbr, GBDSO-B.Mask.gbr, GBDSO-B.SilkS.gbr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]
2019-02-21 added orignal PCB pictures, courtesy of Tauwasser from gbdev discord, see readme
2019-02-21 fixed typo in bom list
2019-03-04 general update and lib fix + new generated gerber
    [GBDSO-B.Cu.gbr, GBDSO-B.Mask.gbr, GBDSO-B.SilkS.gbr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]
2019-03-05 added jumpers to the schematic and pcb so that the EPROM can be programmed on the cartridge
    [GBDSO.kicad_pcb, GBDSO.sch]
2019-03-05 updated schematic with jumpers
2019-03-05 updated readme with information about programming the EPROM on the board + added a few images showing the jumpers and EPROM.
2019-03-05 updated pcb images with new jumpers
2019-03-05 updated gerber and drill files
    [GBDSO-B.Cu.gbr, GBDSO-B.Mask.gbr, GBDSO-B.SilkS.gbr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]
2019-03-06 forgot to add pin 12 and 26 (NC) to the component, now fixed
2019-03-06 new gerber and drill files
    [GBDSO-B.Cu.gbr, GBDSO-B.Mask.gbr, GBDSO-B.SilkS.gbr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]
2019-03-06 updated readme + added schematic-2.png
2019-03-06 updated schematic (now 2 pages) and PCB + adding Gekkio DS Lite footprint
    [GBDSO Cartridge.sch, GBDSO EPROM Adapter Board.sch, GBDSO.kicad_pcb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]
2019-03-06 changed GameBoy cart on the adapter board from Gekkio's footprint to Xunbeifang GNI172 footprint made by obskyr
2019-03-06 updated gerber with new Xunbeifang GB connector
    [GBDSO-B.Cu.gbr, GBDSO-B.Mask.gbr, GBDSO-B.SilkS.gbr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]
2019-03-06 updated schematic, pcb, pictures and readme because I changed the GB connector to the Xunbeifang one
    [GBDSO Cartridge.sch, GBDSO EPROM Adapter Board.sch, GBDSO.kicad_pcb]
2019-03-06 added link to buy xunbeifang connector in readme
2019-03-06 removed gekkio GB connector, now using Xunbeifang GNI172 connector
2019-03-06 bom list has been moved to the bottom of the readme
2019-03-07 fixed edge cuts
    [GBDSO.kicad_pcb]
2019-03-07 generated new gerber files after fixing edge cuts
    [GBDSO-B.Cu.gbr, GBDSO-B.Mask.gbr, GBDSO-B.SilkS.gbr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]
2019-03-07 updated readme and added v0 PCB picture
2019-03-07 cleanup, moving stuff in folder, updating readme and schematic files
2019-03-07 added plcc32 package, update board with new 3D package
    [GBDSO.kicad_pcb]
2019-03-08 updated readme with official pcb dimensions
2019-03-08 fixed link to first pcb picture
2019-03-08 added freecad file and SVG file for the cartridge dimensions
    [pcb dimensions.FCStd]
2019-03-08 added pcb thickness to tech drawing, updated readme
    [pcb dimensions.FCStd]
2019-03-09 modify PCB to match the cart dimensions, update all gerber files, update PCB pictures
    [GBDSO-B.Cu.gbr, GBDSO-B.Mask.gbr, GBDSO-B.SilkS.gbr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]
2019-03-10 renamed file due to typo, moved files to dedicated folder
    [pcb dimensions.FCStd]
2019-03-10 added render of the usage of the adapter board + updated readme with pictures
    [GBDSO 3D model.FCStd]
2019-03-10 updated readme with max voltage ratings
2019-03-10 modified the pads from custom to rectangular, because loading the pcb into freecad triggered an exception
2019-03-10 minor updates
    [GBDSO.kicad_pcb]
2019-03-10 new generated gerber files
    [GBDSO-B.Cu.gbr, GBDSO-B.Mask.gbr, GBDSO-B.SilkS.gbr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]
2019-04-18 increased the size of the pads to make it easier to solder
2019-04-18 Bunch of changes: fixed pin swap on DS1267_SOIC, fixed footprint of all uncorrect ICs, fixed footprint off the three inductors as they were too big. Because of the size change of the footprint of the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
    [GBDSO Cartridge.sch, GBDSO EPROM Adapter Board.sch, GBDSO.kicad_pcb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]
2019-04-19 Fixed wrong measurement in tech drawing
    [pcb dimensions.FCStd]
2019-04-19 Moved small hole to correct position, also had to move C8 and the -5V trace because of the hole.
    [GBDSO.kicad_pcb]
2019-04-20 updated gerber files with latest fixes/improvements to the PCB
    [GBDSO-B_Cu.gbr, GBDSO-B_Mask.gbr, GBDSO-B_SilkS.gbr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]
2019-04-24 pcb v1 pictures
2020-04-02 changed TL062 to TL072, see #14. updated schematic image, see #9.
    [GBDSO Cartridge.sch, GBDSO EPROM Adapter Board.sch, GBDSO.sch]
2020-04-02 Changed TL062 to TL072, #14. Added silkscreen for channels, #8. Updated PCB images, #11
    [GBDSO.kicad_pcb]
2020-04-03 moved C4, C5, C12, C14 to the power pins of the TL072
    [GBDSO Cartridge.sch, GBDSO EPROM Adapter Board.sch, GBDSO.sch]
2020-04-04 fix #16
    [GBDSO Cartridge.sch, GBDSO.kicad_pcb]
2020-04-04 fix #17
    [GBDSO Cartridge.sch]
2020-04-04 issue #16, #17 and #18 are fixed in the schematic but not yet in the PCB
    reopened issue #16 and #17 as they were not yet fixed in the PCB
    [GBDSO Cartridge.sch, GBDSO.kicad_pcb]
2020-04-04 fix #16, fix #17, fix #18 in schematic and PCB
    fixed issues #16, #17, #18 in schematic and PCB, with improvement here and there.
    [GBDSO Cartridge.sch, GBDSO.kicad_pcb]
2020-04-05 made a hand soldered version of the PLCC32 footprint
2020-04-05 Used the new PLCC32 handsolder footprint and moved a few traces around
    [GBDSO Cartridge.sch, GBDSO.kicad_pcb]
2020-12-25 updated gerber
    [GBDSO-B.Cu.gbr, GBDSO-B.Mask.gbr, GBDSO-B.SilkS.gbr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]
2020-12-25 fixed voltage divider at input buffer
    R3-R4, R10-R11 were swapped
    [GBDSO Cartridge.sch]
2020-12-25 added some art and fixed the resistors R3-R4/R10-R11
    [GBDSO.kicad_pcb]
2020-12-25 updated gerber files
    [GBDSO-B_Cu.gbr, GBDSO-B_Mask.gbr, GBDSO-B_SilkS.gbr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]
2020-12-25 small update
    [GBDSO.kicad_pcb]
2020-12-25 increased tab with to 4mm as recommended by jlcpcb eng + updated gerber
    [GBDSO-B_Cu.gbr, GBDSO-B_Mask.gbr, GBDSO-B_SilkS.gbr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]
2020-12-25 minor update
    [GBDSO.kicad_pcb]
2021-01-08 big v2 update, hopefully everything is ok now
    [GBDSO Cartridge.sch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]
2021-01-24 added assembled image
